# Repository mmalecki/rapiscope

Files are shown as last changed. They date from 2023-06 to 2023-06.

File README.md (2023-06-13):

# Rapiscope
The rack and pinion-adjustable, rapidly 3D-printable, Raspberry Pi-based digital microscope for soldering (and more!).

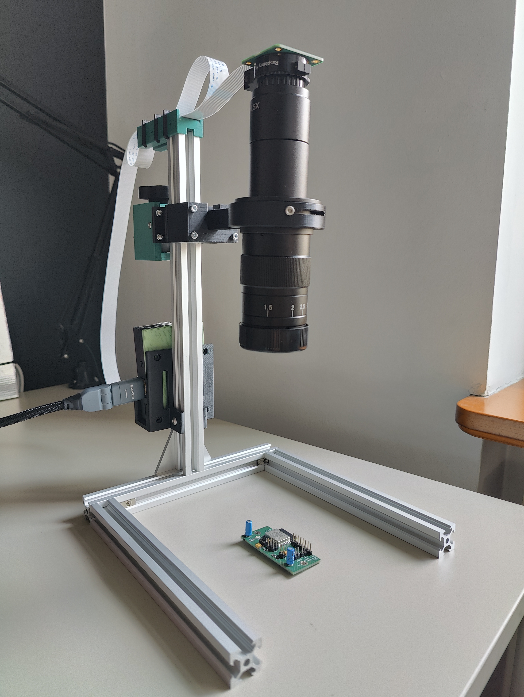
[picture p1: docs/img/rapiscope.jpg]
The Rapiscope


## What is it?
This project uses:
* Raspberry Pi 3 or 4
* Raspberry Pi HQ camera with a C-mount microscope lens
* v-slot aluminium profiles
* a bunch of commodity fasteners and bearings I had laying around

to create a digital microscope with a regulated working distance (and therefore, zoom).

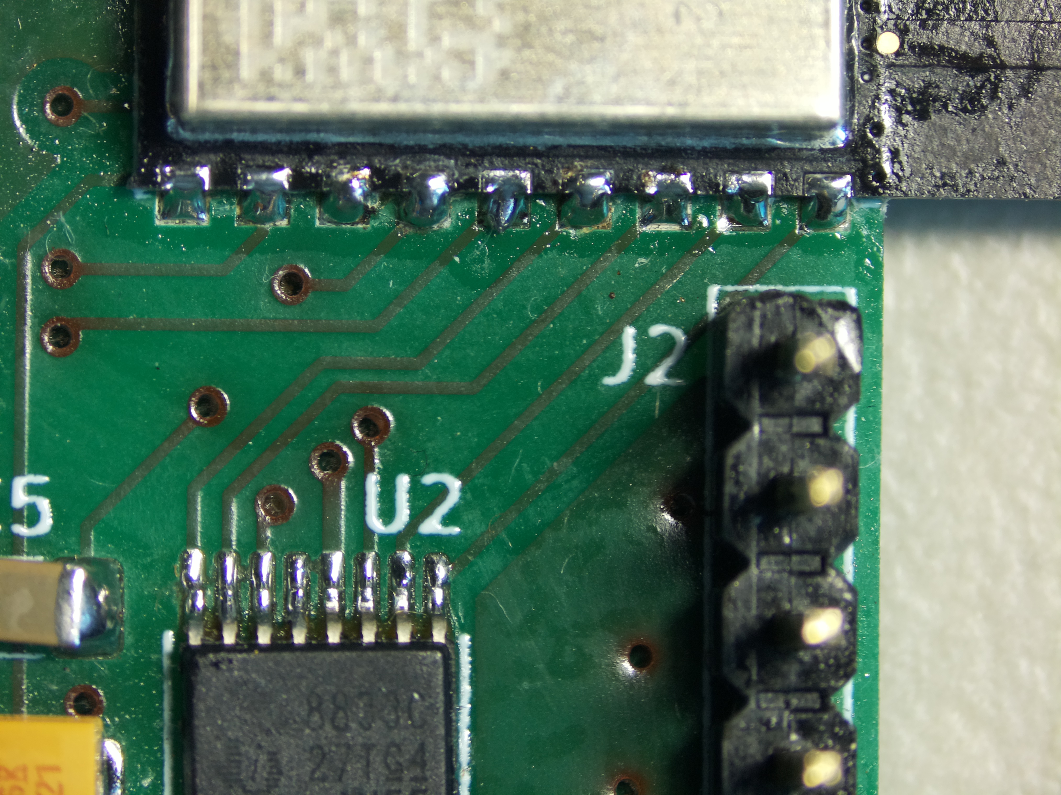
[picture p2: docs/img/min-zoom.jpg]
Minimum zoom image through the Rapiscope

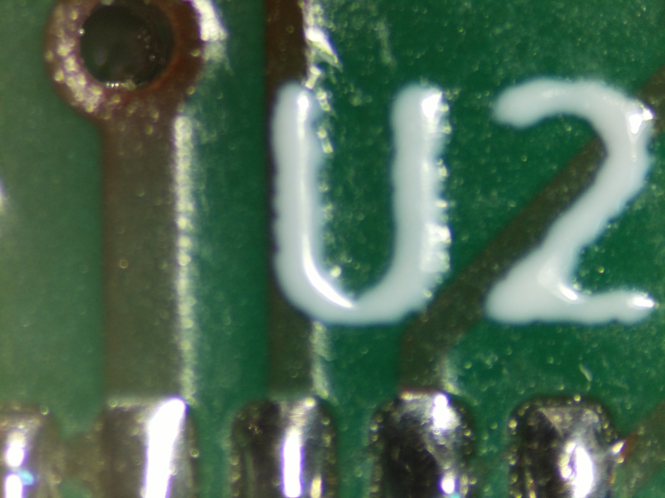
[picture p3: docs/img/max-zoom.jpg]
Maximum zoom image through the Rapiscope


It utilizes a 3D printed version of a mechanism that's been commonplace in analog microscopes
for ages - the [rack and pinion](https://www.microscope-antiques.com/randp.html), driven by a
worm gear to ensure self-locking (knob removed for demonstration purposes):

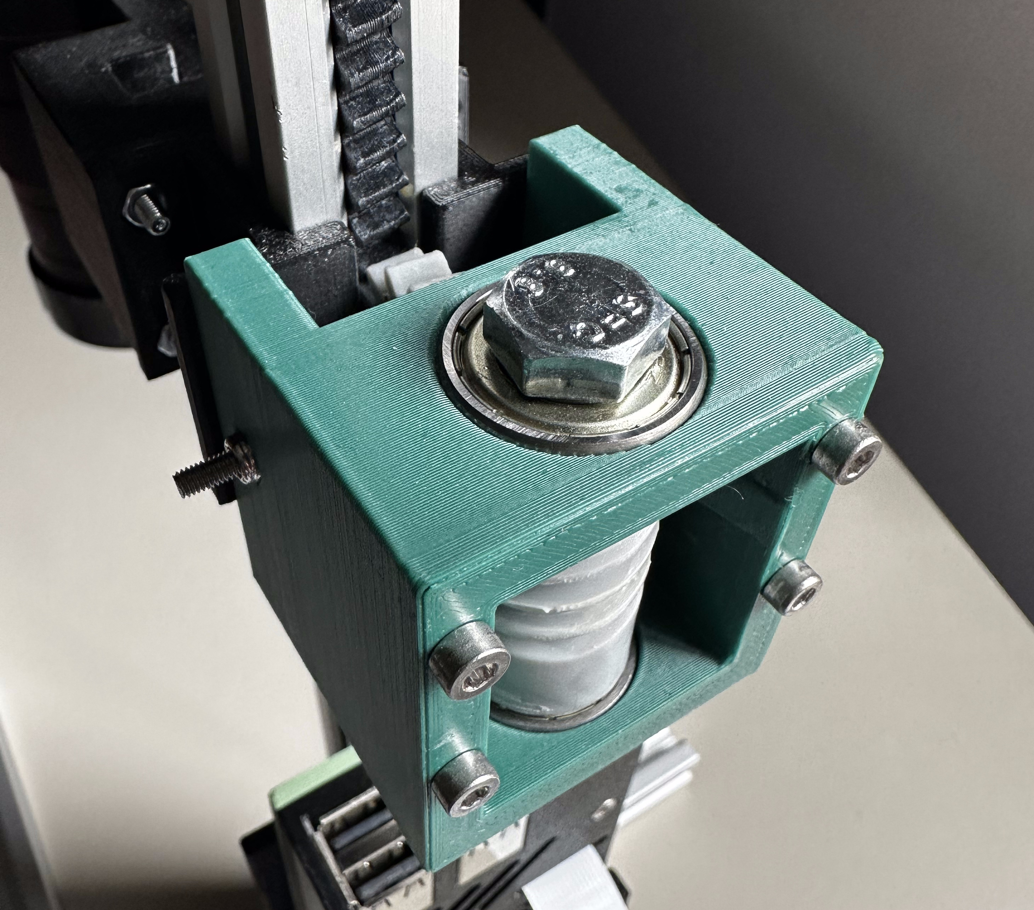
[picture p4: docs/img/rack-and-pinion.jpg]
Rack and pinion


## Motivations

While this entire project can be bought as a unit (be it with a built-in
screen, or only a camera, sometimes with a helping hand) from various manufacturers,
DYI'ing allowed me to build this from reusable and commodity components.

I was also able to introduce a motion system that doesn't rely on me holding the lens as I move it.

Thanks to the use of aluminium profiles for the structure, I will be able to easily
extend this with your usual soldering station suspects - for example, a fume extractor.

Additionally, with the Raspberry Pi on board, I can look both at the thing I'm soldering,
and its schematics, on one screen.

## Building
If you're interested in building the Rapiscope, check out:

* [bill of materials](./docs/bill-of-materials.md)
* [build guide](./docs/build-guide.md)

## Acknowledgements and prior work
* [/u/SilentMobius](https://www.reddit.com/user/SilentMobius/)' [Raspberry Pi Microscope](https://www.reddit.com/r/raspberry_pi/comments/oukppg/raspberry_pi_hq_camera_microscope_v2/)
* [OpenFlexure](https://openflexure.org/projects/microscope/) - this is where to go if you were looking for something more classic microscope-y rather than work-station-microscope-y

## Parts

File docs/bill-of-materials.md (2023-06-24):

# Bill of materials

## Optics
| Part | Quantity | Notes | Links |
| --- | ---: | --- | ----- |
| C-mount microscope lens | 1 | You can use any lens you like, but Z axis lengths are picked for the one linked | [US](https://www.amazon.com/Monocular-C-Mount-Industry-Microscope-Objective/dp/B016NUGHK2) |
| 0.5x Barlow lens | 1 | Optional, but increases the working distance from ~100 mm to ~200 mm | [US](https://www.amazon.com/gp/product/B071G2DSQY) |
| Raspberry Pi HQ camera | 1 | |
| Raspberry Pi camera cable, 80 cm | 1 | The one that comes with the camera is way too short |

## Brains
| Part | Quantity | Notes | Links |
| --- | ---: | --- | ----- |
| Raspberry Pi 3 or 4 | 1 | | |

## Frame
| Part | Quantity | Notes | Links |
| --- | ---: | --- | ----- |
| v-slot 2020, 20 cm | 3 | | |
| v-slot 2020, 30 cm or 40 cm | 1 | If using the recommended lens, pick 40 cm if using the 0.5x Barlow lens or want to keep your options open, and 30 cm otherwise. | |
| T joining plate | 1 | | [PL](https://www.v-slot.pl/pl/p/Plytka-laczeniowa-T/192) 
| 90 degree joining plate | 2 | | [PL](https://www.v-slot.pl/pl/p/Plyta-laczeniowa-90-stopni-do-2020/1820)
| M5x10 | 15 | | | 
| M5 2020 t-nut | 15 | | | 
| M4x10 | 4 | Optional*
| M4 2020 t-nut | 4 | Optional*

*: Used to mount feet.

## Gearbox
| Part | Quantity | Notes | Links |
| --- | ---: | --- | ----- |
| M3x50 | 5 | |
| M3 nyloc nut | 1 | |
| 623zz bearing | 1 | Can be customized for any small bearing with ID = 3 mm |
| M8x50 hex head | 1 | |
| M8 nyloc nut | 1 | |
| 608zz bearing | 2 | |
| plastic-safe grease | as needed | |

## Slider
| Part | Quantity | Notes | Links |
| --- | ---: | --- | ----- |
| M3 nut | 8 | |

## Microscope mount
| Part | Quantity | Notes | Links |
| --- | ---: | --- | ----- |
| M3x40 | 4 | |
| M3x12 | 1 | |

## Raspberry Pi mount
| Part | Quantity | Notes | Links |
| --- | ---: | --- | ----- |
| M4x8 | 2 | |
| M4 2020 t-nut | 2 | |
| M3 nut | 4 | Optional* |
| M3x20 | 4 | Optional* |

*: If you don't have a case for the Raspberry Pi handy, you can mount it
straight onto the mount. Otherwise, you just rest the case inside the mount.

## Printed parts

* **Material**: My build features the rack printed in PC-CF and worm and pinion printed
  in resin, because I wanted to see what would happen. They're functioning well so far.
  For general use, when PC-CF is not available, I would recommend PETG. What it lacks in
  rigidity, it makes up in its failure mode of deforming instead of becoming brittle
  and cracking.
* **Layer height**: At most 0.2 mm layer height (recommend using [variable layer height](https://help.prusa3d.com/article/variable-layer-height-function_1750)
* **Infill**: 15%
* **Perimeters**: 3

The up-to-date models can be found on [Printables](https://www.printables.com/model/505840-rapiscope) or the latest [GitHub releases](https://github.com/mmalecki/rapiscope/releases).

| Part | Quantity | Notes |
| --- | ---: | --- |
| housing | 1 |
| pinion | 1 |
| rack | 1 | Pick the version appropriate for your Z axis length, 140 mm for 30 cm and 240 mm for 40 cm |
| slider | 1 |
| worm | 1 |
| knob | 1 |
| microscope-mount  | 1 | 
| microscope-holder | 1 | Requires supports |
| rpi-mount | 1 |
| top-cable-clip | 1 | |
| top-cable-guide | 3 | Optional, you can also use zip ties |
| foot | 4 | Optional, material: TPU
| endcap | 2 | Optional

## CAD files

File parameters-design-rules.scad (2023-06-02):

use <catchnhole/catchnhole.scad>;

bolt = "M3";

press_fit = 0;
tight_fit = 0.1;
fit = 0.2;
v_slot_sliding_fit = 0.021;  // H7/h6 over a 20 mm "shaft"
loose_fit = 0.5;

bolt_wall_min_d = 3.6;
bolt_wall_d = bolt_diameter(bolt) + bolt_wall_min_d;

bearing_wall_min_d = 5;
v_slot_wall_min_t = 4;

fastener_wall_min_h = 1.6;  // Minimum thickness of a wall alongside fastener axis.
nut_wall_min_d = 4;

nut_wall_h = nut_height(bolt) + fastener_wall_min_h;
nut_wall_d = nut_width_across_corners(bolt) + nut_wall_min_d;

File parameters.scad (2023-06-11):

// These are the main parameters you can modify to tweak your rapiscope.

// Width of the gears (this is the width of the v-slot extrusion slot):
w = 6;

// Gear module:
m = 1.5;

// The length of the rack for the Z axis motion system.
// The default here applies to the 30 cm long Z axis, set 240 mm here if
// using a 40 cm long Z axis.
rack_l = 140;
slider_bolt_s = 20;  // Spacing of the slider mounting bolts.

/* [ Worm ] */
// We're using bolts as shafts here, so our length choices are limited. We're therefore
// going to drive parts of the worm design off the shaft length.

// Bolt size to use as shaft:
worm_shaft = "M8";
// Shaft length:
worm_shaft_l = 50;

// We use the 608 bearing for the worm by default:
// Height of the worm bearing:
worm_bearing_h = 7;
// Internal diameter of the worm bearing (we don't currently handle a case where
// this is different than the worm bearing shaft, but it should amount to a single
// `cylinder`, the previous version did it):
worm_bearing_id = 8;
// Outer diameter of the worm bearing:
worm_bearing_od = 22;

/* [ Pinion ] */
// Bolt size to use as shaft:
pinion_shaft = "M3";

// How many teeth the pinion gear should have:
pinion_teeth = 16;

// Outer diameter of the pinion bearing.
pinion_bearing_od = 10;
// Height of the pinion bearing.
pinion_bearing_h = 4;

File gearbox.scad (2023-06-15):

include <parameters-design-rules.scad>;
include <parameters.scad>;
include <v-slot/parameters.scad>;
use <catchnhole/catchnhole.scad>;
use <gears/gears.scad>;
use <v-slot.scad>;
use <v-slot/v-slot.scad>;

// Error correction for OpenSCAD flickering.
ec = 0.01;

/* [ Worm ] */
thread_starts = 2;
lead_angle = 10;

worm_bearing_holder_d = worm_bearing_od + bearing_wall_min_d;
worm_shaft_nut_h = nut_height(worm_shaft, kind = "hexagon_lock");
worm_shaft_nut_wall_d = nut_width_across_corners(worm_shaft) + nut_wall_min_d;

// Worm mount:
//
// Length of the mount at the bottom of the shaft:
worm_shaft_mount_h = worm_shaft_nut_h + fastener_wall_min_h;
// Length of the worm gear itself:
worm_length = worm_shaft_l - 2 * worm_bearing_h - worm_shaft_mount_h;

worm_r = m * thread_starts / (2 * sin(lead_angle));  // From gears/gears.scad.

bearing_z = [ worm_length / 2, -worm_length / 2 - worm_shaft_mount_h - worm_bearing_h ];

pinion_d = m * pinion_teeth;

/* [ Rack ] */
// Length of the rack (120 mm for 300 mm long v-slot, 220 mm for 400 mm):
rack_mount_bolt_l = 8;
rack_mount_d = rack_mount_bolt_l;

// TODO: `rack_mount_d` can likely be derived from design rules

// Rack mount bolt.
rack_mount_bolt = "M4";
// Measured cam height of the M4 t-nut.
rack_mount_t_nut_cam_h = 1;
// Measured clearance the M4 t-nut needs to rotate in the v-slot slot.
rack_mount_t_nut_clearance = 11.5;
rack_mount_h = rack_mount_t_nut_clearance + nut_wall_min_d;

/* [ Slider ] */
// Thickness of the slider wall:
slider_t = v_slot_wall_min_t;
slider_d = v_slot_d + 2 * v_slot_wall_min_t;
// Spacing of the slider mounting bolts in Z axis (X is determined by design rules):
slider_bolt_s = 20;
slider_bolt_x_s = slider_d + nut_wall_d;
slider_h = slider_bolt_s + nut_wall_d;

/* [ Housing ] */
housing_t = bolt_wall_d;
housing_w = slider_d / 2 + nut_wall_d / 2 - housing_t / 2;
housing_h = worm_shaft_l;
housing_l = worm_bearing_holder_d / 2 + pinion_d - slider_t + worm_r;
housing_z_offset = -worm_shaft_mount_h / 2;

/* [ Print ] */
bolt_hole_sacrificial_layer = 0.2;
part = "";  // ["", "housing", "worm", "pinion", "rack", "slider"]

$fn = part == "worm" ? 64 : 128;

function slider_h () = slider_h;

// Housing outer width:
function housing_ow () = (housing_w + housing_t) * 2;

echo("Slider bolt X spacing:", slider_bolt_x_s);
echo("Housing length:", housing_l);
echo("Housing internal width:", housing_w * 2);
echo("Housing outer width:", housing_ow());
echo("Worm bearing holder length: ", worm_bearing_holder_d);

module gearbox_housing () {
  gearbox_housing_half();
  mirror([ 1, 0, 0 ]) gearbox_housing_half();
}

module gearbox_rib (a_x, a_y, b_x0, b_x1, b_y, h) {
  b_x2 = b_x0 + b_x1 + a_x;

  translate([ 0, 0, -h / 2 ]) linear_extrude(h) {
    polygon([ [ 0, 0 ], [ a_x, a_y ], [ b_x0 + a_x, b_y ], [ b_x2, b_y ], [ b_x2, 0 ] ]);
  }
}

module gearbox_worm_to_worm_bearings (top = true, bottom = true) {
  // XXX: full of hacks to get the bearing properly rotated for assembly instructions.
  // We're in the middle of the worm gear right now.
  b_z = concat(top ? [bearing_z[0]] : [], bottom ? [bearing_z[1]] : []);
  for (z = b_z) {
    translate([ 0, 0, z + (z == bearing_z[1] ? worm_bearing_h : 0) ]) {
      mirror(z == bearing_z[1] ? [ 0, 0, 1 ] : [ 0, 0, 0 ]) children();
    }
  }
}

module gearbox_worm_to_worm_bolt () {
  translate([ 0, 0, bearing_z[1] ]) children();
}

module gearbox_housing_half () {
  difference() {
    union() {
      translate([ -housing_w - housing_t, -housing_l - slider_t, housing_z_offset ])
        cube([ housing_t, housing_l, housing_h ]);

      gearbox_to_drive_train() {
        gearbox_to_worm() {
          gearbox_worm_to_worm_bearings() {
            translate([ 0, -worm_bearing_holder_d / 2 ])
              cube([ housing_w, worm_bearing_holder_d, worm_bearing_h ]);
          }
        }

        pinion_spacer_h = housing_w - w / 2 - tight_fit;
        pinion_spacer_d = bolt_diameter(pinion_shaft) + bolt_wall_min_d;
        rib_w = housing_l;
        translate([ -housing_w, -slider_t - rib_w ]) mirror([ 0, 1 ]) rotate([ 0, 0, 270 ])
          gearbox_rib(
            housing_l / 2,
            housing_w - worm_r -
              m,  // Length and height of first section (trying to avoid the worm gear)
            housing_l / 2 - pinion_d / 2 + slider_t - pinion_spacer_d / 2,
            pinion_spacer_d,  // Length and height of the final section (building up to
                              // the pinion gear spacer)
            pinion_spacer_h,  // Height of the final section
            pinion_spacer_d   // Width of the rib itself
          );
      }
    }

    translate([ -housing_w - housing_t / 2, 0, housing_h / 2 ]) {
      for (side = [ 1, -1 ]) {
        translate([ 0, 0, side * slider_bolt_s / 2 ]) {
          rotate([ 90, 0, 0 ])
            bolt(bolt, length = housing_l + slider_t, kind = "socket_head");
        }
      }
    }

    gearbox_to_drive_train() {
      gearbox_to_worm() {
        gearbox_worm_to_worm_bearings() {
          translate([ 0, 0, -ec ])
            cylinder(d = worm_bearing_od + press_fit, h = worm_bearing_h + ec * 2);
        }
      }
      gearbox_to_pinion() {
        gearbox_pinion_to_mount() {
          nutcatch_parallel(pinion_shaft);
          bolt(pinion_shaft, length = (housing_w + housing_t) * 2);
        }
      }
    }
  }
}
module gearbox_to_worm () {
  translate([ 0, -worm_r - pinion_d, 0 ]) children();
}

module gearbox_to_pinion () {
  translate([ 0, -pinion_d / 2 ]) rotate([ 90, 0, -90 ]) children();
}

module gearbox_pinion_to_mount () {
  translate([ 0, 0, housing_w + housing_t ]) {
    rotate([ 180, 0, 0 ]) children();
  }
}

module gearbox_pinion () {
  difference() {
    translate([ 0, 0, -w / 2 ]) {
      spur_gear(
        m, pinion_teeth, w, bore = bolt_diameter(pinion_shaft) + fit, optimized = false,
        helix_angle = -lead_angle
      );
    }
    translate([ 0, 0, -pinion_bearing_h + w / 2 ])
      cylinder(d = pinion_bearing_od, h = pinion_bearing_h);
  }
}

module gearbox_worm () {
  l_fit = worm_length - fit;
  mount_h = worm_shaft_mount_h;

  // Center around the drive train point:
  translate([ 0, 0, -l_fit / 2 - mount_h ]) {
    difference() {
      union() {
        cylinder(d = max(worm_shaft_nut_wall_d, 2 * (worm_r + m)) - m / 3, h = mount_h);
        translate([ 0, 0, mount_h ])
          worm(m, thread_starts, l_fit, bolt_diameter(worm_shaft), lead_angle = lead_angle);
      }

      nutcatch_parallel(worm_shaft, kind = "hexagon_lock");

      difference() {
        translate([ 0, 0, -worm_bearing_h ])
          bolt(worm_shaft, length = worm_shaft_l, kind = "socket_head");
        if (bolt_hole_sacrificial_layer != 0) {
          translate([ 0, 0, worm_shaft_nut_h ])
            cylinder(d = bolt_diameter(worm_shaft), h = bolt_hole_sacrificial_layer);
        }
      }
    }
  }
}

module worm_assembly () {}

module slider () {
  d = slider_d;
  linear_extrude(slider_h) {
    difference() {
      square([ d, d ], center = true);
      translate([ -v_slot_slot_outer_w / 2, -d / 2 ])
        square([ v_slot_slot_outer_w, v_slot_wall_min_t ]);
      v_slot_2d_clearance(fit = loose_fit);
    }
    v_slot_2d_slider(loose_fit);
  }

  slider_mount_panes();
}

module slider_mount_panes () {
  // This is pretty convoluted.
  for (side_x = [ 1, -1 ]) {
    for (side_y = [ 1, -1 ]) {
      translate([
        side_x * (slider_d / 2 + nut_wall_d / 2),
        side_y * (slider_d / 2 - nut_wall_h / 2),
      ]) {
        difference() {
          translate([ -nut_wall_d / 2, -nut_wall_h / 2 ]) {
            cube([ nut_wall_d, nut_wall_h, slider_h ]);
          }
          translate([ 0, 0, slider_h / 2 ]) {
            for (nutcatch_side_z = [ 1, -1 ]) {
              translate([ 0, 0, nutcatch_side_z * slider_bolt_s / 2 ]) {
                rotate([ side_y == 1 ? 90 : 270, 0, 0 ]) {
                  nutcatch_parallel(bolt);
                  rotate([ 0, 180, 0 ]) bolt(bolt, length = nut_wall_h);
                }
              }
            }
          }
        }
      }
    }
  }
}

module gearbox_rack_mount () {
  translate([ -w, -(rack_mount_d - v_slot_slot_h) ]) {
    difference() {
      cube([ w, rack_mount_d, rack_mount_h ]);
      translate([ w / 2, rack_mount_d, rack_mount_h * 3 / 4 ]) rotate([ 90, 90, 0 ]) {
        bolt(rack_mount_bolt, rack_mount_bolt_l, kind = "socket_head");
        cylinder(
          h = v_slot_slot_h - (v_slot_slot_cam_h - rack_mount_t_nut_cam_h - tight_fit),
          d = rack_mount_t_nut_clearance
        );
      }
    }
  }
}

module gearbox_rack () {
  mx = m / cos(lead_angle);  // copied from gears/gears.scad
  translate([ w / 2, 0 ]) {
    translate([ 0, 0, mx ]) mirror([ 0, 0, 1 ]) gearbox_rack_mount();
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

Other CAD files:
knob.scad
assemblies/gearbox.scad
assemblies/vitamins/fasteners.scad
v-slot.scad

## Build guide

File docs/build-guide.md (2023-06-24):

# Build guide

## Protips
* The ["screw pulling technique"](https://help.prusa3d.com/guide/1-introduction_176529#176814) will help you get your nuts into tricky places.
* Use a flat surface to make sure the bearings fit properly.

## Printing instructions
[Check out the bill of materials](./bill-of-materials.md) for 3D printing settings.

## Gearbox
* 1 x housing
* 2 x 608zz bearing
* 1 x M8x50 hex head
* 1 x worm
* 1 x M8 nyloc nut
* 1 x knob
* 1 x pinion
* 1 x 623zz bearing
* 1 x M3x50
* 1 x M3 nut
* plastic-safe grease (I used white lithium grease from WD-40, but silicone grease should do as well)

### Worm gear
Clean out the worm gear's sacrificial layer (the thin wall between the nutcatch and bolt hole).

Start by inserting the bearing into the top bearing holder.

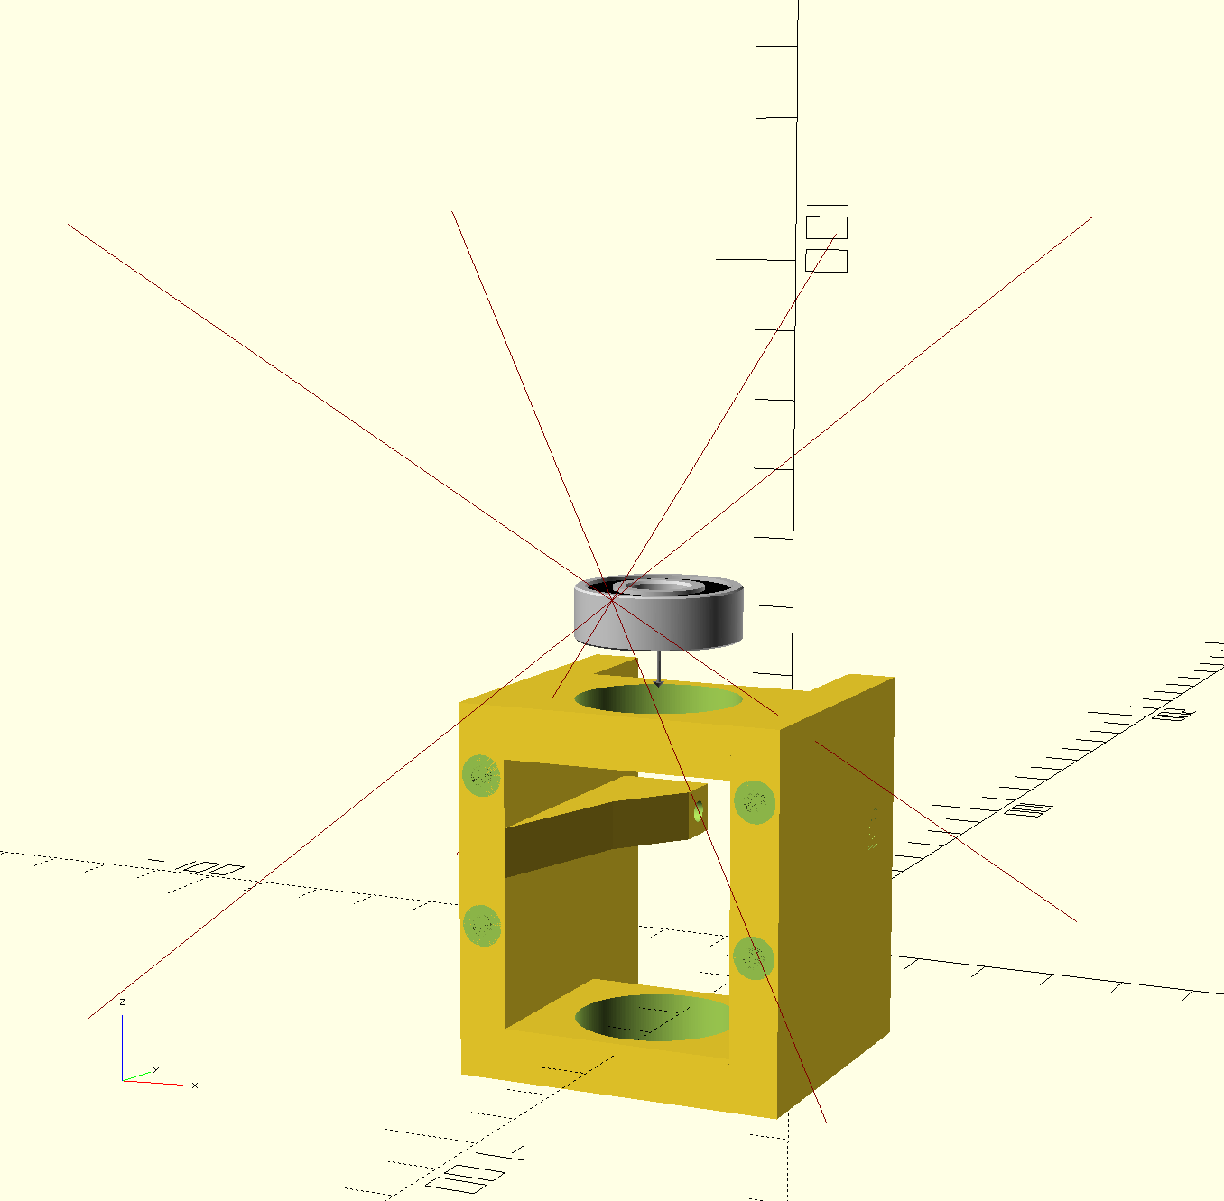
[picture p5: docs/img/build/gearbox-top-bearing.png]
Insert the bearing into the top bearing holder


Next, pass the M8x50 hex head bolt through the top bearing, head facing up. 

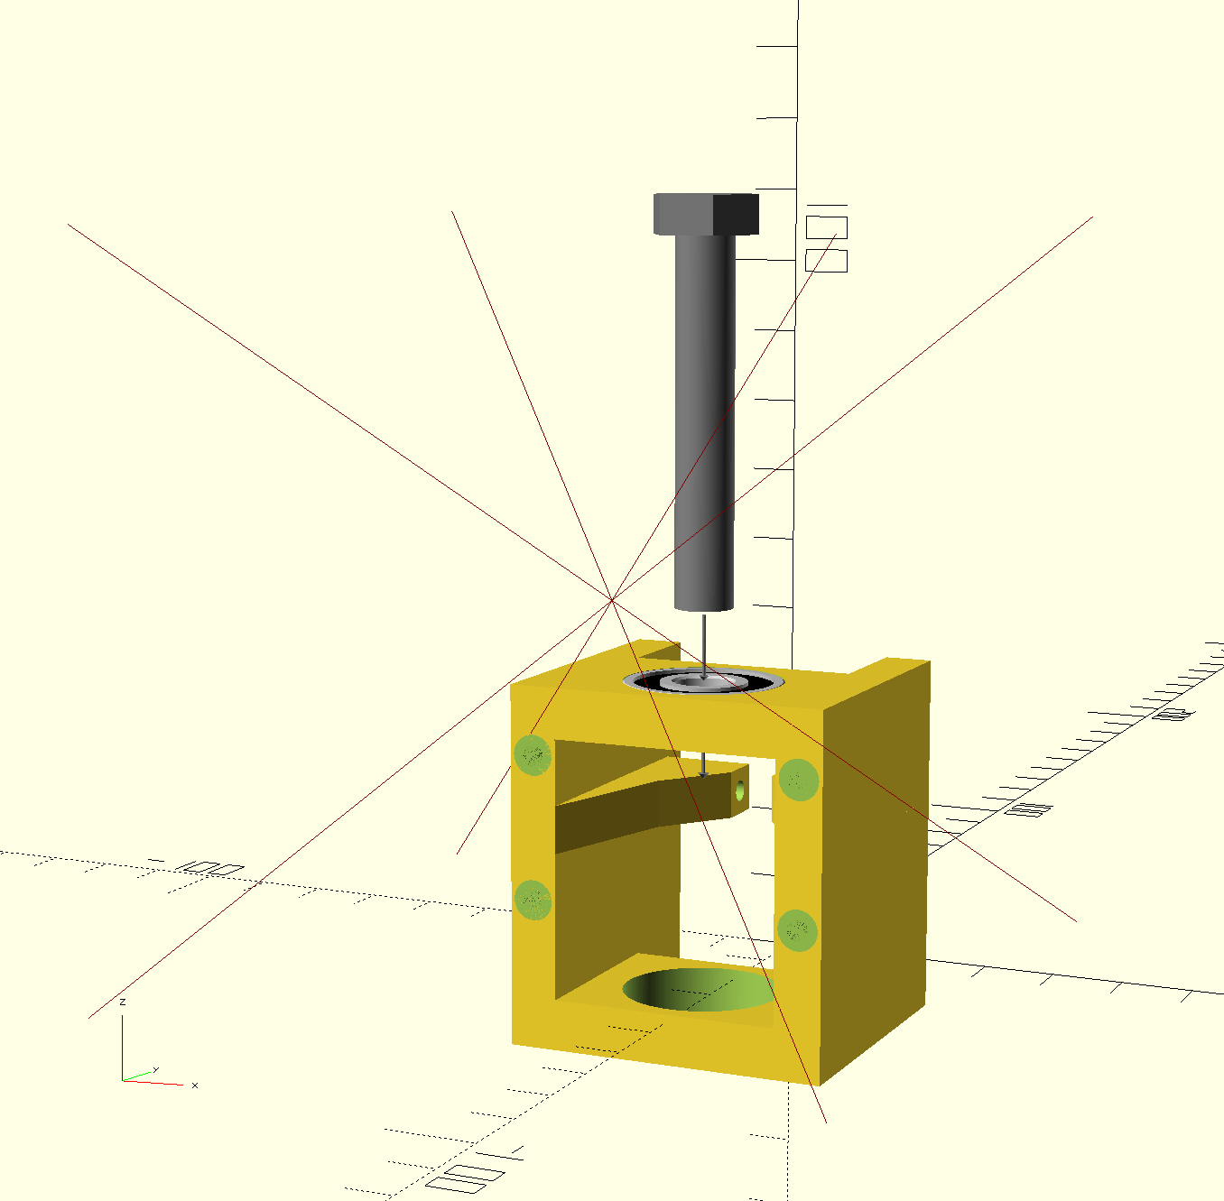
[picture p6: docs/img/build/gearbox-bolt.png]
Insert the M8x50 hex head bolt through the top bearing

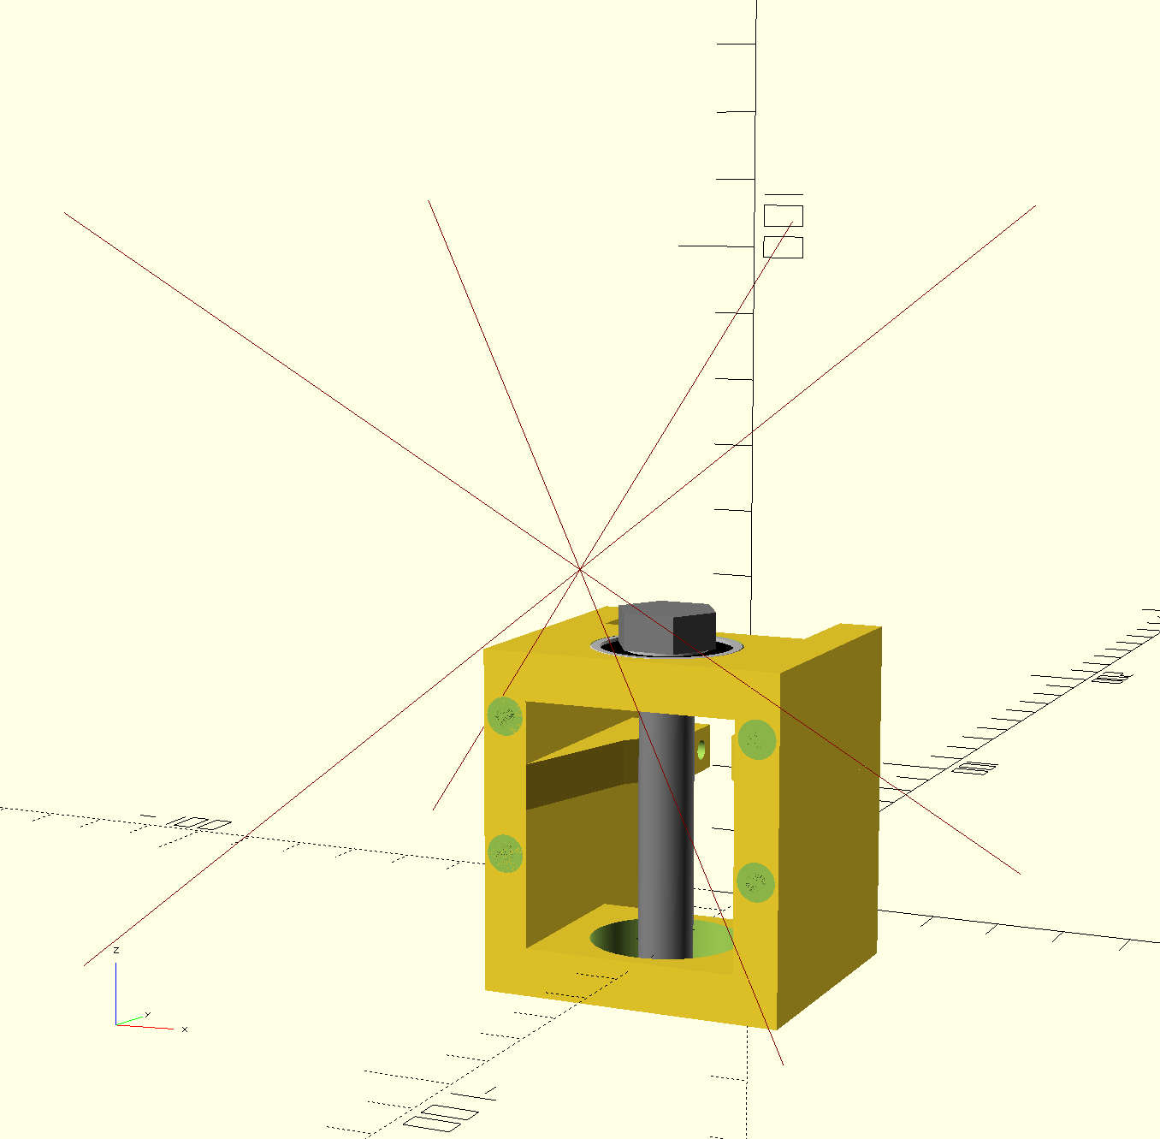
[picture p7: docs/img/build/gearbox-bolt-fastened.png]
M8x50 hex head bolt in its position, through the top bearing


Place the worm gear on the bolt, nut side down.

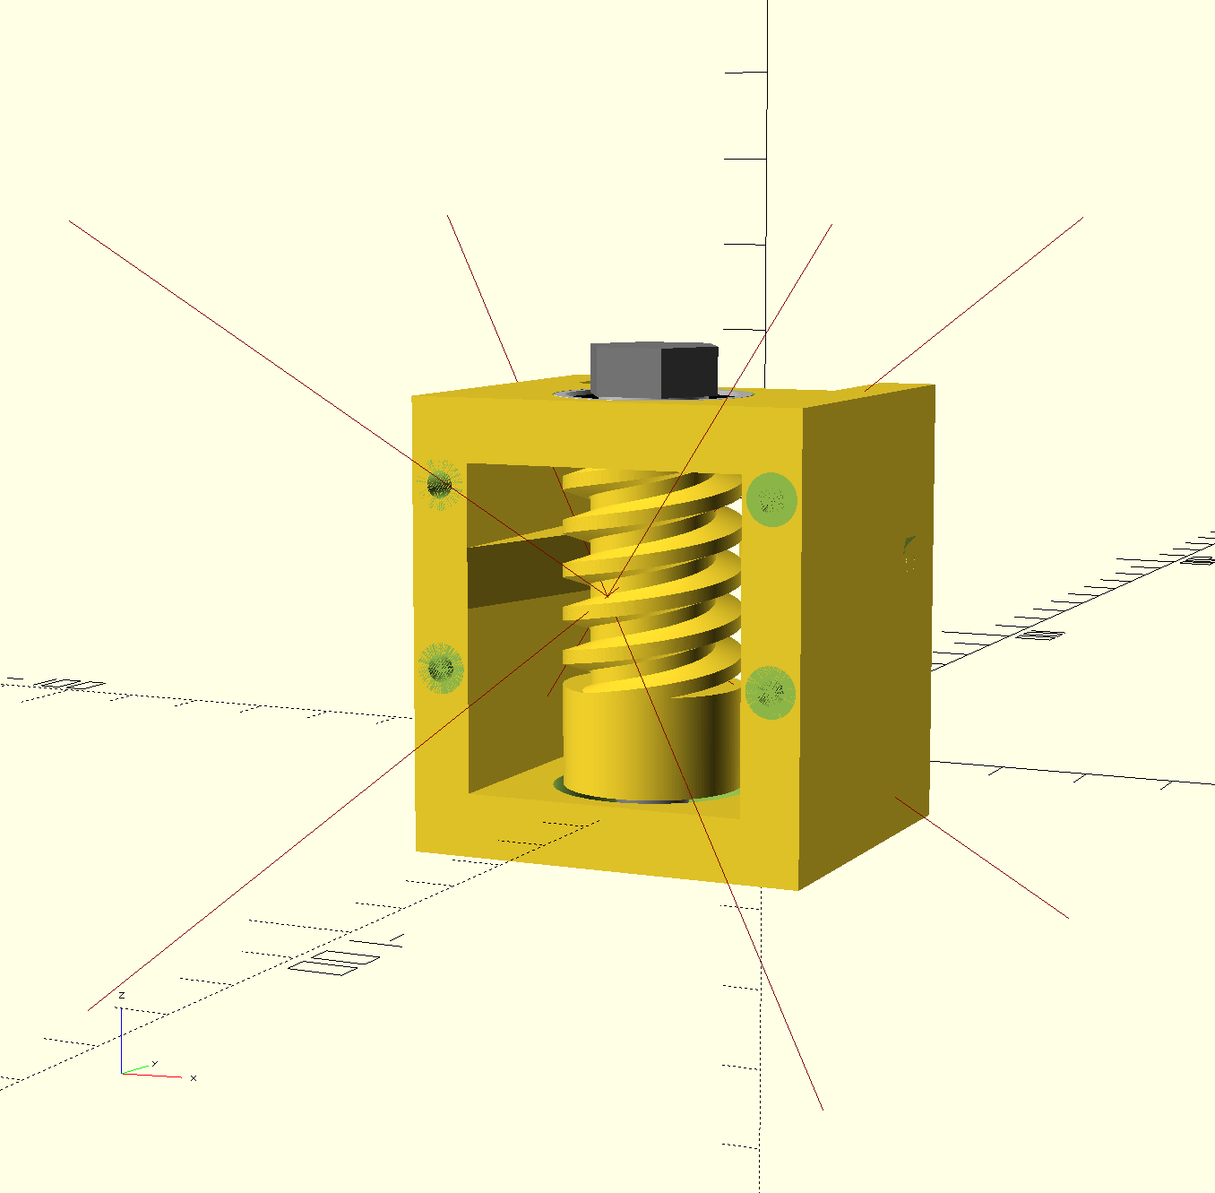
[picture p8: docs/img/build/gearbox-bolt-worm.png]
M8x50 hex head bolt with the worm gear


Thread the M8 nyloc nut, circular side facing down, onto the bolt. Move the worm gear to capture the nut, and then,
holding the worm gear with your hand so that it doesn't rotate, use either a spanner wrench, or the knob, to fasten
the bolt until the worm gear is in place: just below the bearing, but not in contact with it and able to rotate freely
(this step is finicky and requires some strength and dexterity, next version will address this).

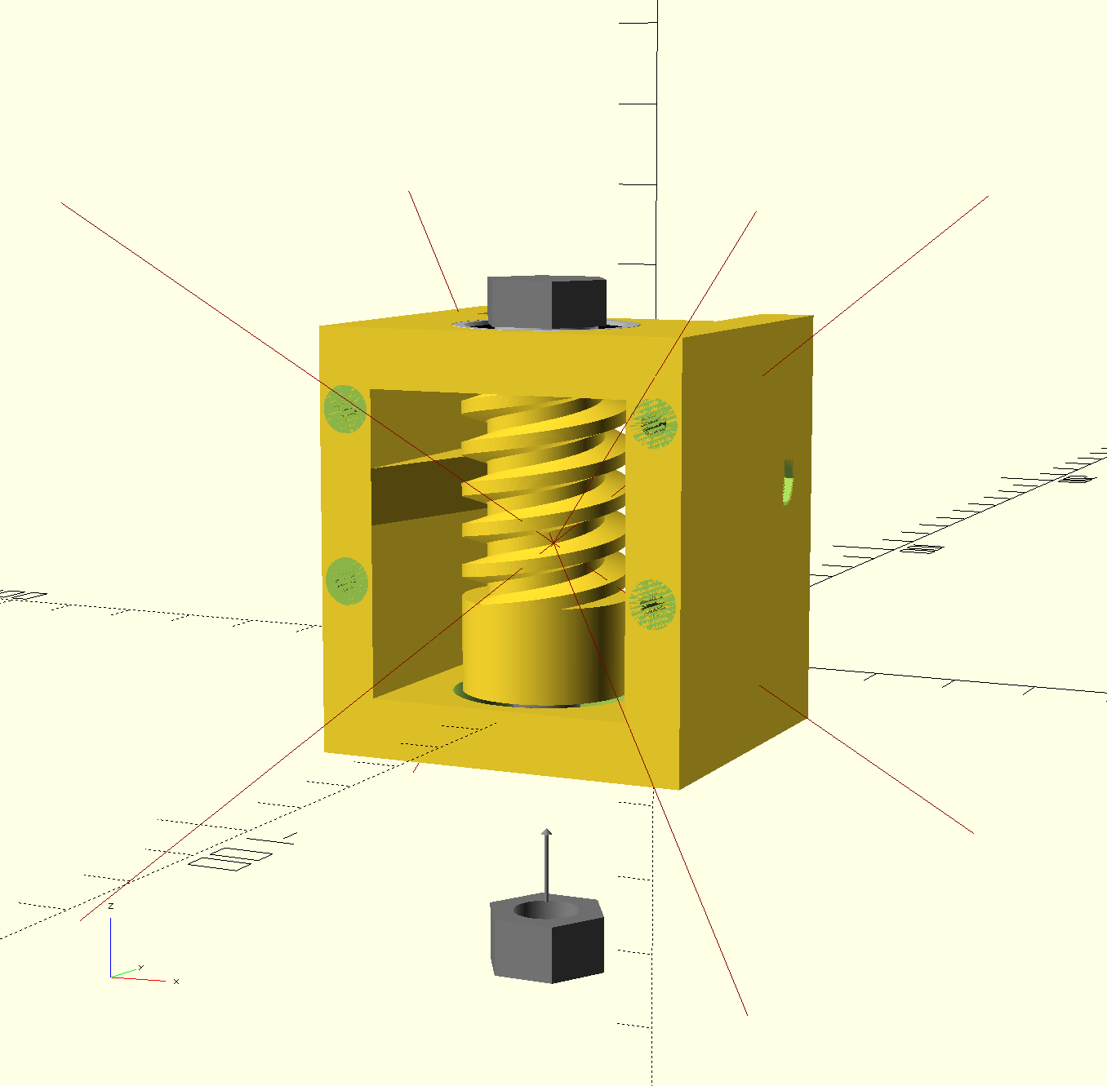
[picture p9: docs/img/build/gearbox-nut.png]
Thread the nut onto the M8x50 hex head bolt


Insert the bottom bearing into the bottom bearing holder, onto the bolt.

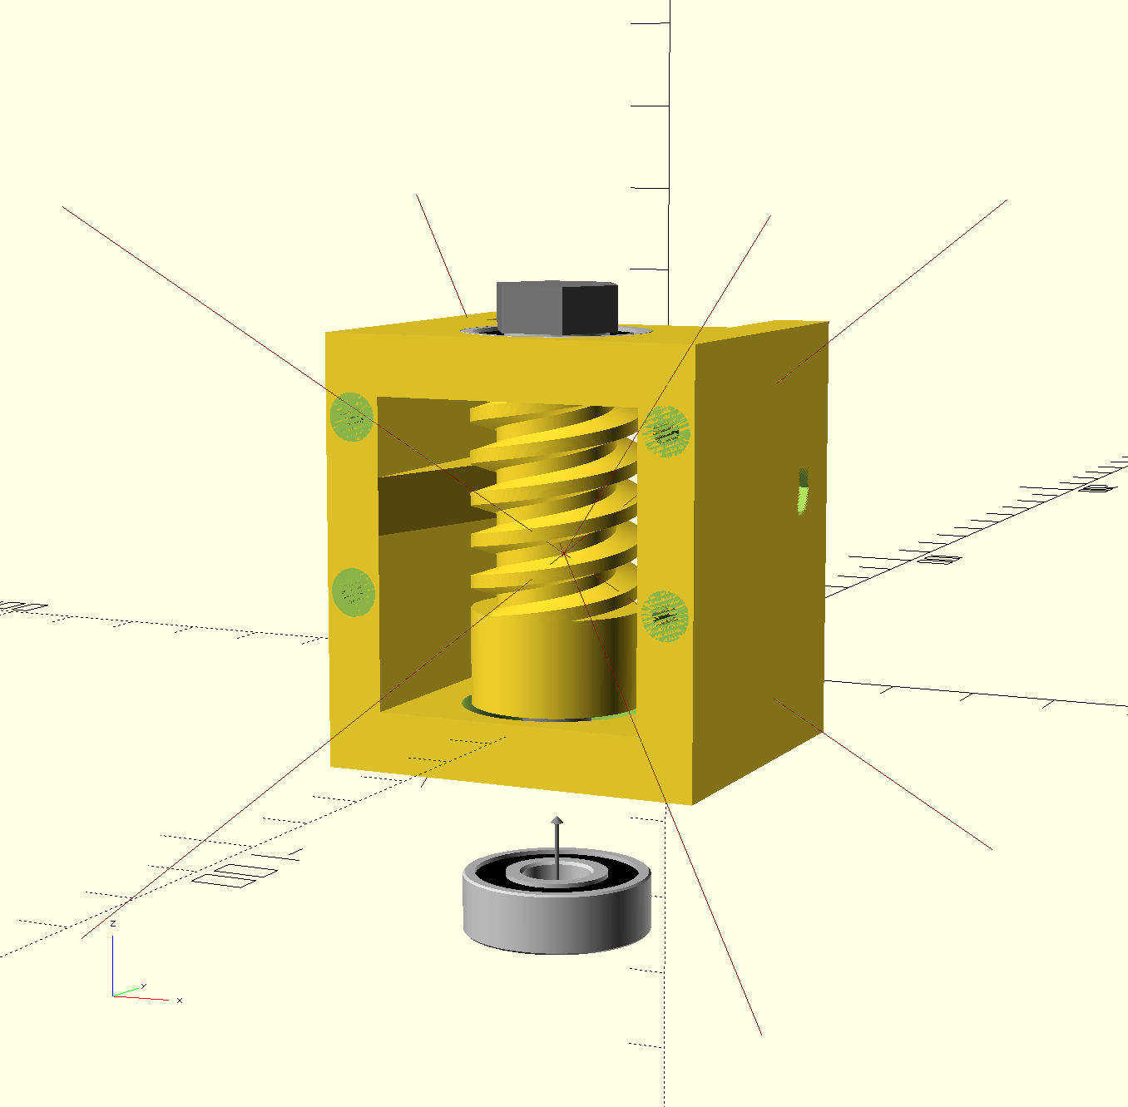
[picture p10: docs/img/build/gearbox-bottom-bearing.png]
Insert the bearing into the bottom bearing holder


### Pinion gear
Insert the 623zz bearing into the pinion gear. 

Insert the pinion gear into its place, and secure with the M3x50 bolt and nut (orientation doesn't matter).
Make sure to not overtighten - ensure the gear can rotate freely when the worm gear is rotated.

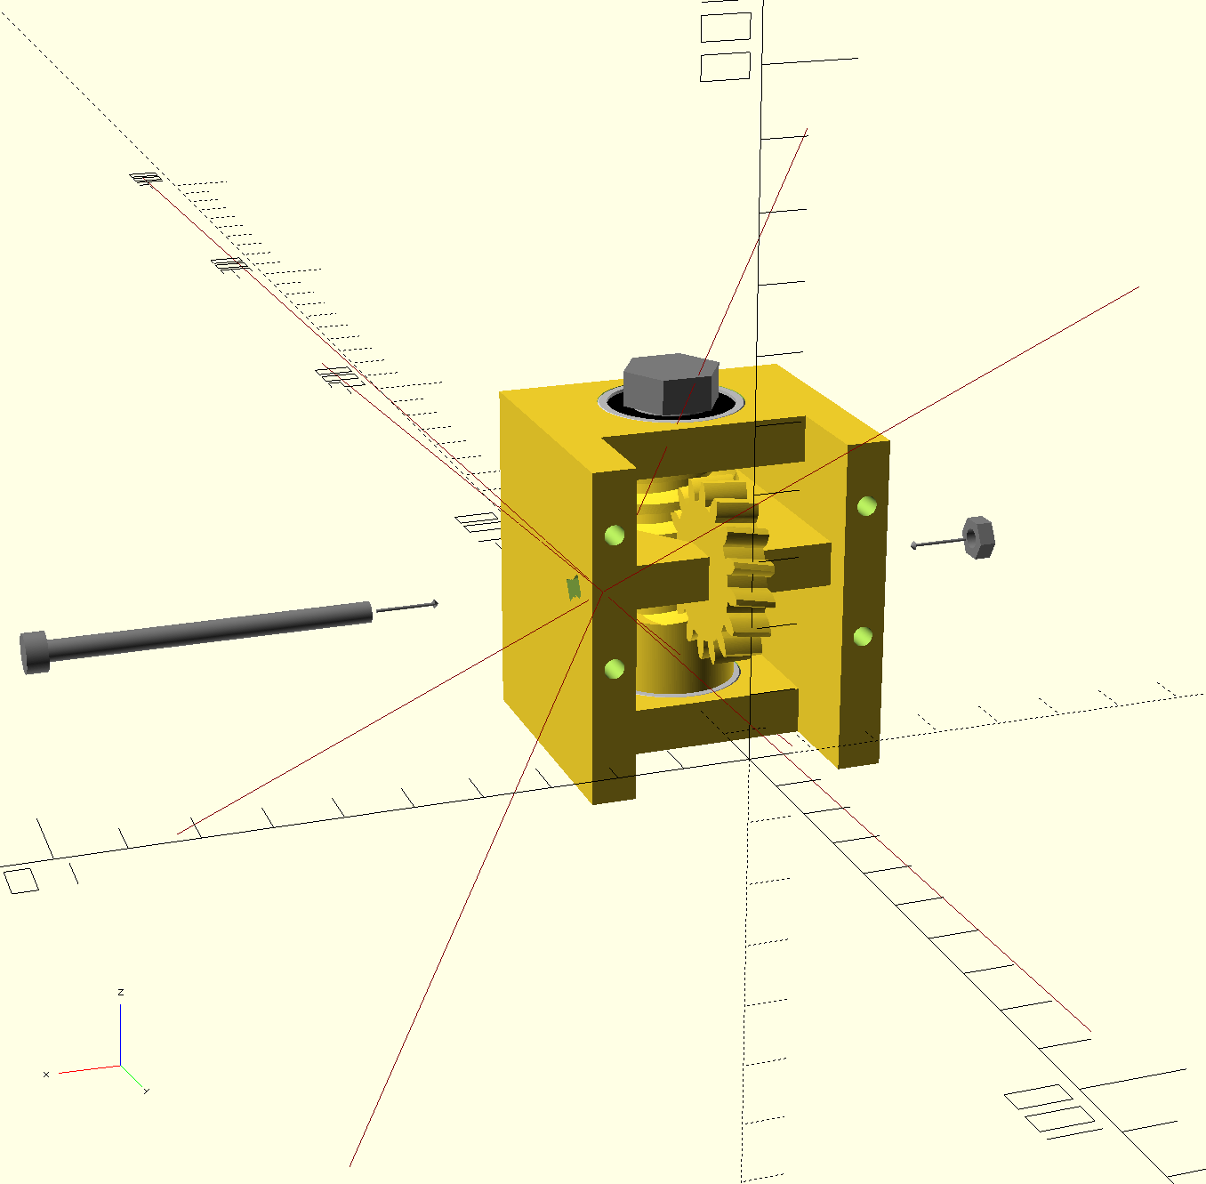
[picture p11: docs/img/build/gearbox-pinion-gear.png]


That's it, you're done!

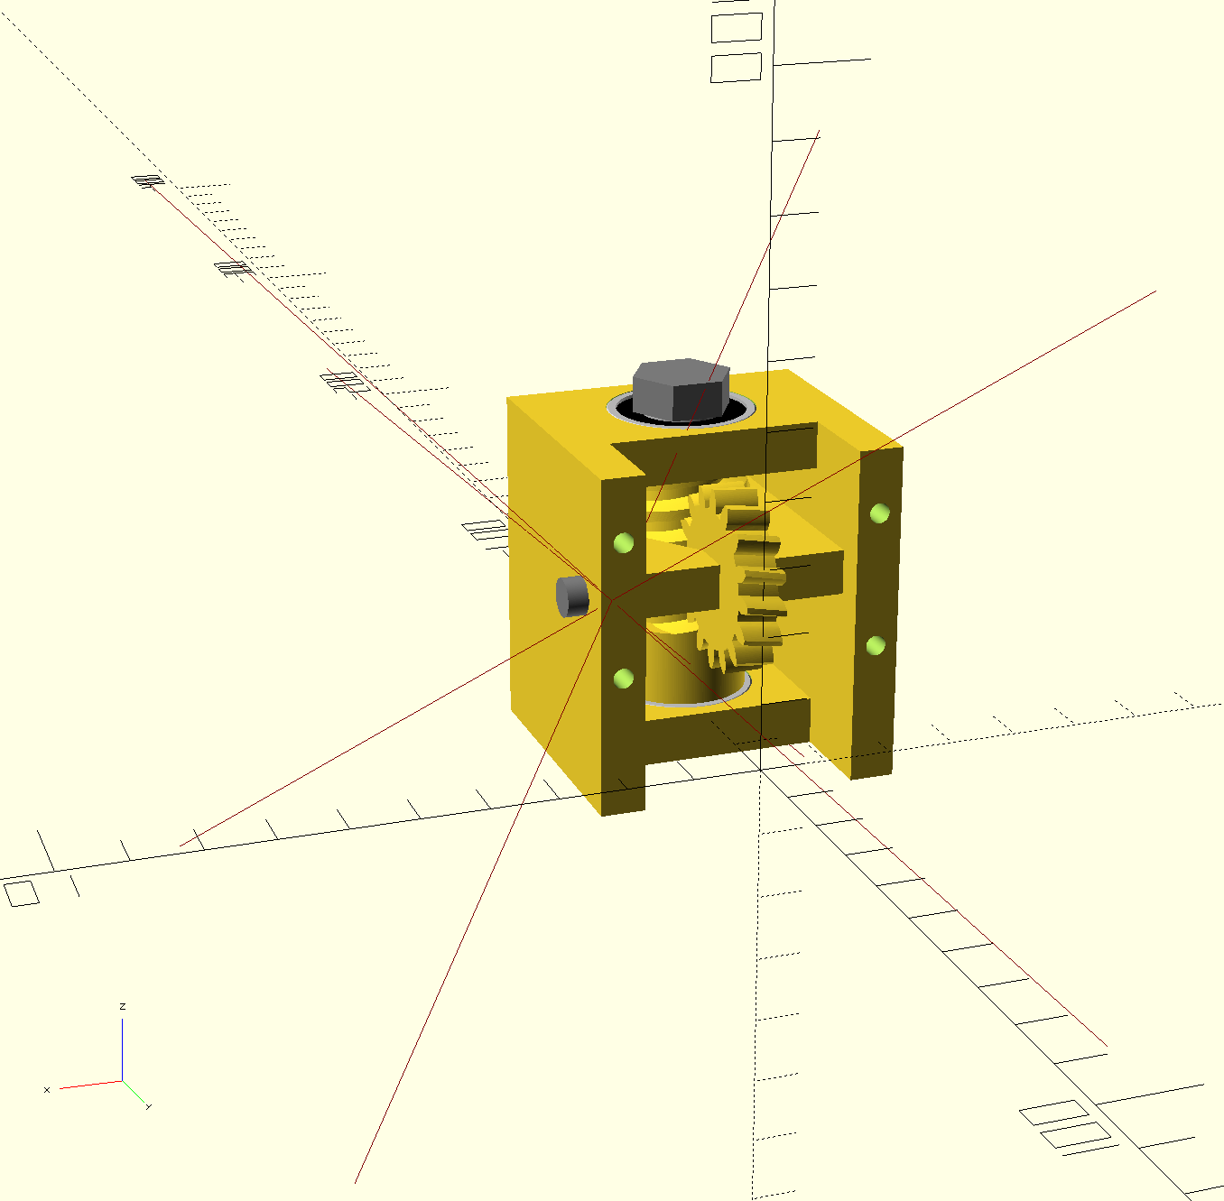
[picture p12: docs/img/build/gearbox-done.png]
Assembled gearbox


**Lubricate your gearbox. I cannot stress this enough. Depending on the material, without lubrication, the lifetime of your gearbox will get impractically low.** Keep in mind we're holding onto a fair amount of weight and money here.

## Frame
* 3 x v-slot 2020, 20 cm
* 2 x 90 degree joining plate
* 1 x v-slot 2020, 30 cm or 40 cm
* 1 x T joining plate
* 15 x M5x10
* 15 x M5 2020 t-nut
* 4 x foot, optional
* 4 x M4x10, optional
* 4 x M4 t-nut, optional
* 2 x endcap, optional

First, put together the base of the frame. Join the three 20 cm v-slot extrusions using the two 90 degree joining plates to form a "U".
The envelope of the "U" will be our microscope's working field.

If using, mount the feet using the M4x10 bolts and t-nuts: two to the bottom of the "U", and two at the ends of the prongs.
If using, press fit the endcaps at the ends of the prongs. They will help guard against cuts from the sharp edges of extrusions.

Next, mount the Z axis 2020 v-slot to the extrusion at the bottom of the "U", pointing up, using the T joining plate.

## Raspberry Pi mount
* rpi-mount
* 2 x M4x8
* 2 x M4 t-nut

Mount the rpi-mount, facing away from the working field, onto the Z axis extrusion just above the T joining plate, using the M4x8 bolts and t-nuts.

## Motion system
* [Gearbox](#gearbox)
* 1 x knob
* 1 x rack
* 1 x slider
* 2 x M4x8
* 2 x M4 t-nut
* 4 x M3 nut
* 4 x M3x50

Start by mounting the rack, facing away from the working field, onto the Z axis extrusion, with its top some 5 mm below the end of the extrusion.
Secure it with the two M4x8 bolts and t-nuts.

Place the slider on the Z axis extrusion, noting the clearance for the rack. Slide it down to the middle of the rack, so that you're able to mount the gearbox.

(Protip: you can temporarily secure the slider in place by placing a bolt and a t-nut below it.)

Place the M3 nuts in the nutcatches on the side facing away from the workfield.
Secure the gearbox, hex bolt head up, onto the slider with the four M3x50 bolts.

If you didn't yet, now is the time to place the knob on the hex bolt head.

## Microscope mount
* 1 x microscope-mount
* 4 x M3 nut
* 4 x M3x40

Place the M3 nuts in the nutcatches on the side facing the workfield.
Place the microscope-mount on the slider, the clearance for the holder facing up. Secure with the four M3x40 bolts.

## Top cable guide
* 1 x top-cable-guide

Place the top cable guide on top of the Z axis extrusion, the longer part facing away from the working field.
(Protip: if your camera ribbon cable is too long for your Z axis length, fold it underneath the cable clip.)

## Optics
* 1 x Raspberry Pi HQ camera [with the C-CS adapter installed](https://datasheets.raspberrypi.com/hq-camera/c-mount-lens-guide.pdf)
* 1 x C-mount microscope lens
* 1 x Raspberry Pi camera cable, 80 cm
* 1 x Raspberry Pi 3 or 4
* 1 x microscope-holder
* 3 x top-cable-clip (optional, you can also use zip ties)
* 1 x M3x12 

[Disconnect the existing camera cable from the camera and connect the longer one. Connect it to the Raspberry Pi.](https://www.raspberrypi.com/documentation/accessories/camera.html#connecting-the-camera)
Mount the Raspberry Pi HQ camera on the C-mount microscope lens.
Place the lens in the holder. Secure with the M3x12 bolt.
Route the ribbon cable through the top cable guide and secure with the clips or zip ties.

## First run
Start up the Raspberry Pi. Once it boots up, run the command:

```sh
libcamera-vid -t 0 --rotation 180 -f
```

It should open a window previewing what the camera is seeing. Use the height adjustment and zoom adjustment to focus the image.

There it is, that's Rapiscope!

---
If you run into any issues while making Rapiscope, please don't hesitate to e-mail me!

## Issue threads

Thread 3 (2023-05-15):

Housing needs additional worm support

mmalecki, 2023-05-15:
Current lack of constrainment causes the drive gear to slip under load.

mmalecki, 2023-05-17:
Done, much sturdier.

Closed 2023-05-17.

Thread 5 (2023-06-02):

Route the cable through the microscope mount?

mmalecki, 2023-06-02:
We could route the camera ribbon cable through the microscope mount. This would shorten the cable, but would require a A-A cable (as opposed to RPi camera's default, A-B), and moving the Pi to the front of the Z pillar.

If we want to avoid RPi encroaching on work area, we would need to use a 2040 (instead of 2020) for the base extrusion.

mmalecki, 2025-03-21:
This will be solved by angled cable routing as I rework the Pi mounting situation + extrusion joining to provide more travel in the axis.

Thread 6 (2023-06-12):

Gearbox assembly

mmalecki, 2023-06-12:
Current gearbox assembly requires a fair amount of strength and leaves one with a part that's very hard to disassembly. We should figure out if we can split the gearbox housing into two, allowing for worm gear assembly outside of the gearbox.

mmalecki, 2025-09-18:
Ditching this entirely.

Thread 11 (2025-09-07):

Angled Raspberry Pi mount

mmalecki, 2025-09-07:
Such a simple way to avoid cable management hell.

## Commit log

2023-05-14 Add resin printing-related file formats to `.gitignore`
2023-05-14 Add the `gears` submodule
2023-05-14 Add the motion system
    [gearbox.scad, parameters-design-rules.scad, parameters.scad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]
2023-05-15 Add a microscope lens mount
2023-05-16 Beef up the gearbox
    With the microscope as lens, the worm shaft translates out of the way.
    We should add a second constraint points.
    This is still WIP.
    [gearbox.scad]
2023-05-16 Mount the pinion with a rib
    [gearbox.scad]
2023-05-16 Lower the rack mount a little, it seems to separate sometimes
    [gearbox.scad]
2023-05-16 Remove debug code
    [gearbox.scad]
2023-05-19 Fix rack mount positioning by stealing more code from `gears`
    [gearbox.scad]
2023-05-24 Show the objects and the assembly
2023-05-24 Add a wider mounting slot
2023-05-24 Fix the assembly constraint
2023-05-24 The 2D slot has nothing to do with circumference
2023-05-25 Add first iteration of the Raspberry Pi mount
2023-05-25 Basic exporting for print (orientation TODO)
    [gearbox.scad]
2023-05-26 Clean up and add comments to gearbox parameters
    [gearbox.scad]
2023-05-26 Move the rack mountpoints to the edge
    [gearbox.scad]
2023-05-27 Add the top camera cable guide
2023-05-27 Correct variable naming
    [gearbox.scad]
2023-05-27 Longer top cable guide, add a cable clip
2023-05-28 Break out the gearbox assembly into a separate file
    [gearbox.scad, parameters.scad]
2023-05-28 Add a scope-side zip-tie channel to the top cable guide
2023-05-28 Fix `parameters.scad` syntax error
    Export `rack_l`.
    [parameters.scad]
2023-05-28 Fix `tight_fit`, add `press_fit`
    [parameters-design-rules.scad]
2023-06-02 Continue gearbox assembly work
    `s/housing_d/housing_l`
    Error correction for OpenSCAD flickering with bearing negative volumes.
    Arrows.
    [gearbox.scad]
2023-06-02 Extend the top camera cable guide more
2023-06-02 Add our knob
    [knob.scad]
2023-06-02 Correct axis lengths
    The fastener wall height should be the same, really.
    [gearbox.scad, parameters-design-rules.scad, parameters.scad]
2023-06-02 Document some `gearbox.scad` parameters
    [gearbox.scad]
2023-06-06 Increase the `e`
    [gearbox.scad]
2023-06-11 Add fasteners to the assembly
    [fasteners.scad, gearbox.scad, parameters.scad]
2023-06-12 Offset the arrows from fasteners
    [fasteners.scad]
2023-06-12 Add the pinion fasteners
    Explode the gearbox from the rail.
    [gearbox.scad]
2023-06-12 Break out the slider mount panes
    [gearbox.scad]
2023-06-13 Fix drawing only the bottom bearing
    [gearbox.scad]
2023-06-13 Do not show pinion fasteners when disabled
    [gearbox.scad]
2023-06-13 Output OpenSCAD exports in print rotation
    [gearbox.scad]
2023-06-14 Lower the `$fn`
    128 is the maximum recommended value.
    [gearbox.scad]
2023-06-14 Fix `part` customizer
    [gearbox.scad]
2023-06-14 Mention the plastic-safe grease in the BOM
2023-06-14 Note the sacrificial layer on the worm gear
2023-06-14 Stop displaying the basket in `rpi-mount`
    Align the naming.
2023-06-15 Force the worm to `$fn = 64`
    Otherwise it's too much for Prusa Slicer.
    [gearbox.scad]
2023-06-15 Note the materials, cross-link
